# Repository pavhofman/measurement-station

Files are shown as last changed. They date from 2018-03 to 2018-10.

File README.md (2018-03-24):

# Audio Measurement Workstation
## Initial Specifications
- Class II appliance - no ground loops incl. display
- Balanced inputs for measuring bridged or digital amps
- Dedicated device
- Decent measurement quality - PCI soundcard ESI Juli@

## Design Overview
### Thin Client PC FS Futro S900N
- Class II power adapter
- PCI slot incl. +12/-12V supply voltages
- Dual core CPU to allow measurement and VNC remote access
- Connectors for two SATA drives to allow increasing reliability/repairability with RAID1 configuration
- No monitor, keyboard, mouse - access via network VNC
- Current IP address relayed via speech synthesis announcements, using internal soundcard and speaker.
- Inexpensive from ebay

### ESI Juli@
- Both balanced and single-ended inputs and outputs, functioning simultaneously. It allows feeding an amp with single-ended signal and measure balanced speaker output at the same time.
- Digital outputs/inputs for extra measurements/tests
- Full support in linux
- Priced moderately on ebay due to lack of PCI slots in modern PCs

### Software
- Linux Mint Mate (v. 18 at the time of writing)
- Arta measurement software running under wine
- Control - python script hooked to ACPI power button.
  - At startup - Etherner and/or wifi IP addresses are announced.
  - Pushing the power button once - IP addresses announced
  - Pushing the power button twice within two seconds - shutting down + announcement

### Operation
- Measurement mode - remotely via VNC on another PC
- Admin mode - possible to connect monitor/keyboard/mouse at any time

## Construction
All parts are 3D printed, FreeCAD sources and STL models are included in design folder.

Since the thin client supports only half-size PCI cards, room/holes must be made for full-sized one. Upper sound jacks and PS/2 slot must be removed/sawn off.

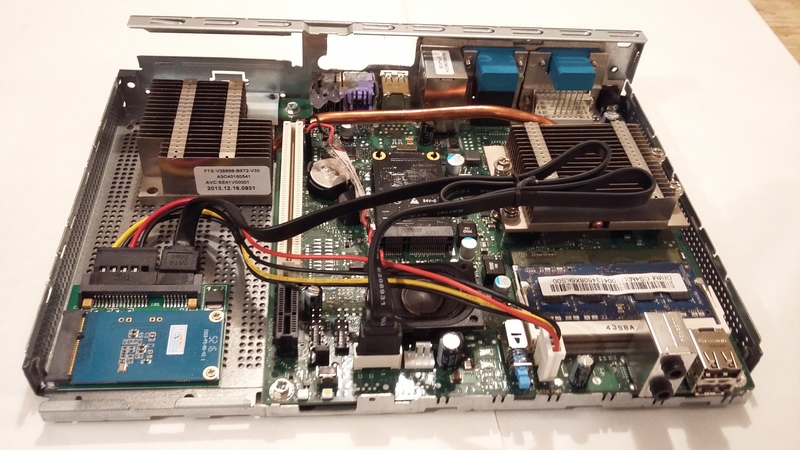
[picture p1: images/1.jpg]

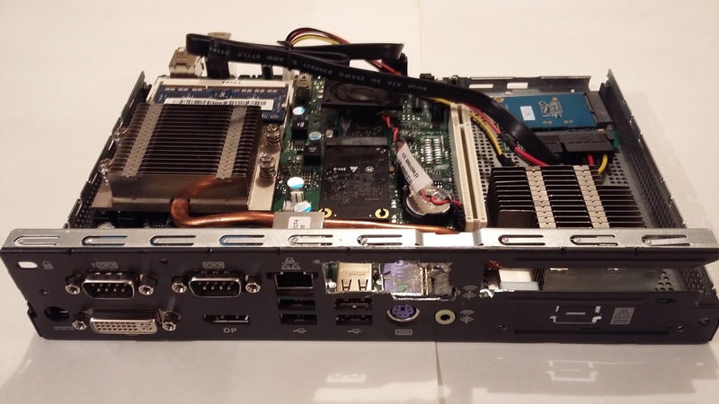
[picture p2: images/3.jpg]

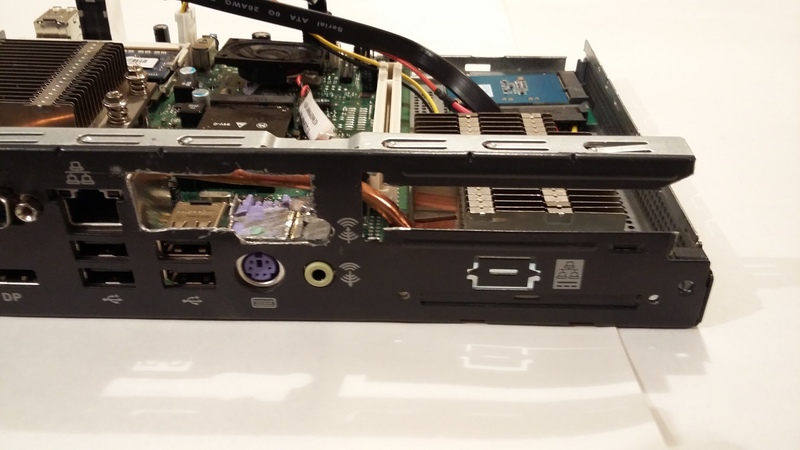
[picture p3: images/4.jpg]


The original holder of the secondary heat sink must be removed, the heat sink fixed directly to the bottom with a new holder.
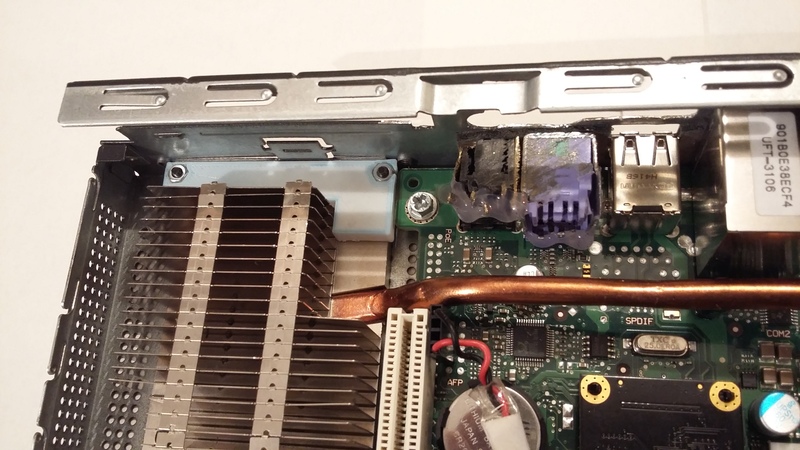
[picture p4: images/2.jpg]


The soundcard is connected with a PCI cable adapter (https://www.aliexpress.com/wholesale?SearchText=19cm+PCI+extension+cable). It is mounted with 3D-printed brackets. The lower brackets provide only shielding, using copper tape connected to the PC enclosure.
Coax digital input and output are extracted from the multiconnector socket to individual add-on cinches.

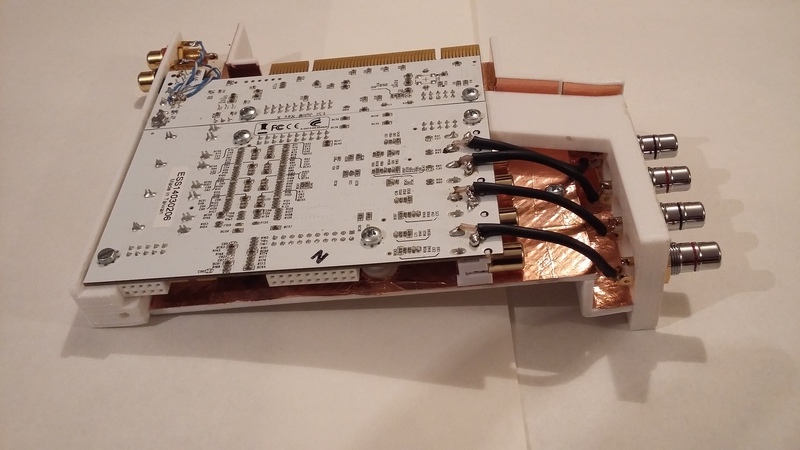
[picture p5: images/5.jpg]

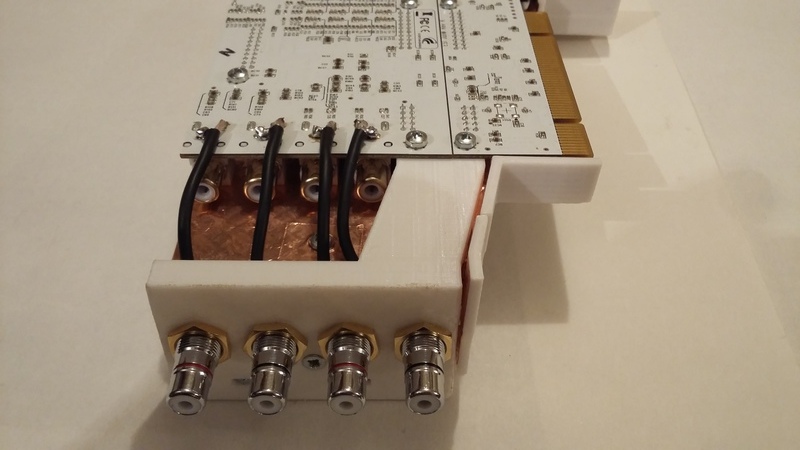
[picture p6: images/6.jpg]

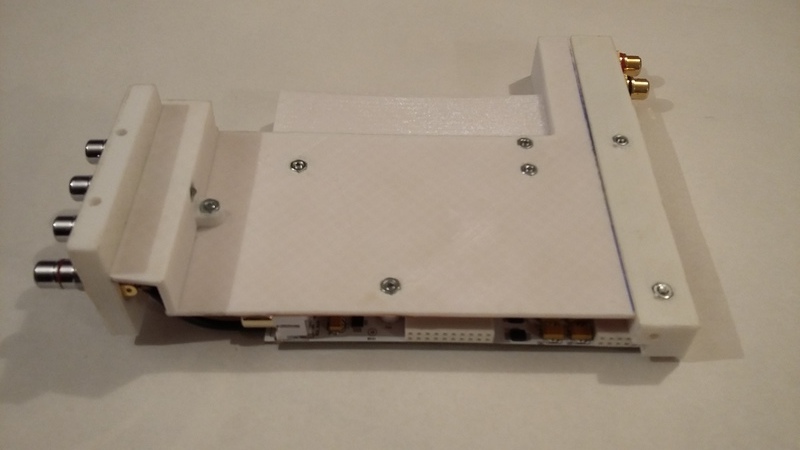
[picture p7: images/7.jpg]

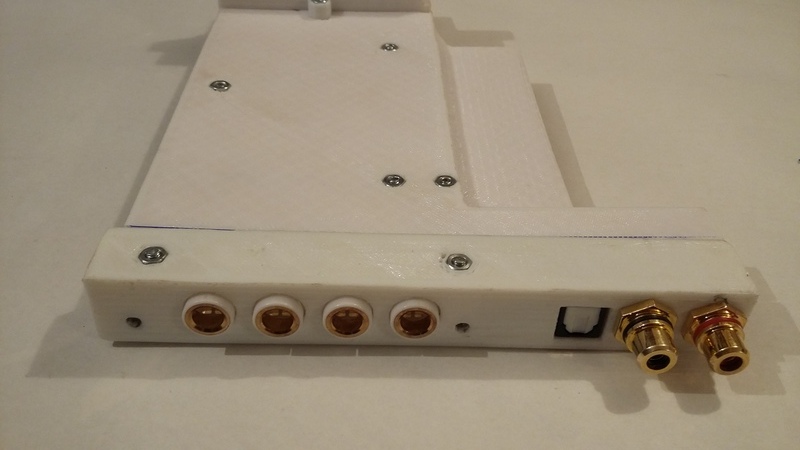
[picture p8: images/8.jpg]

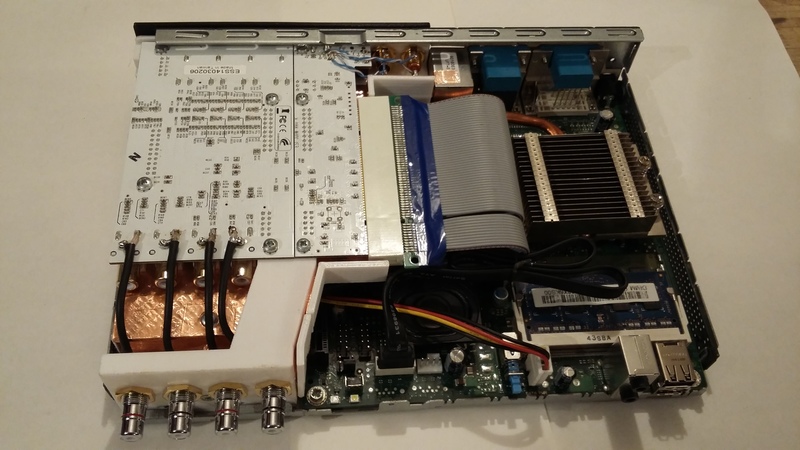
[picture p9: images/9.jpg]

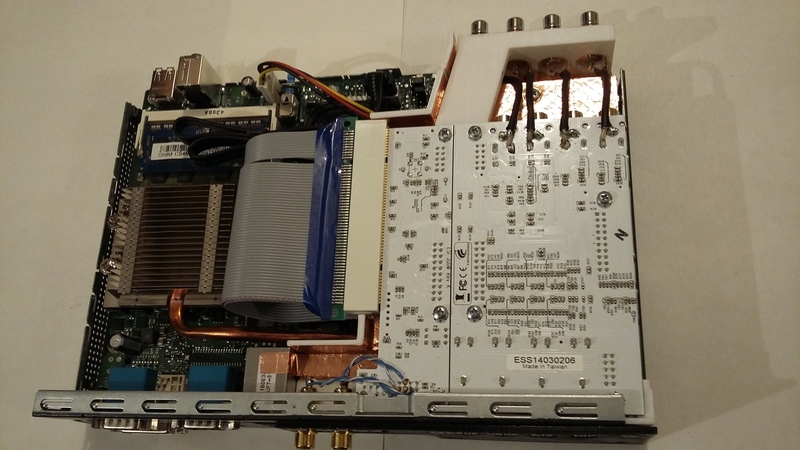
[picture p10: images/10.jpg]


The back panel is printed in two colors.
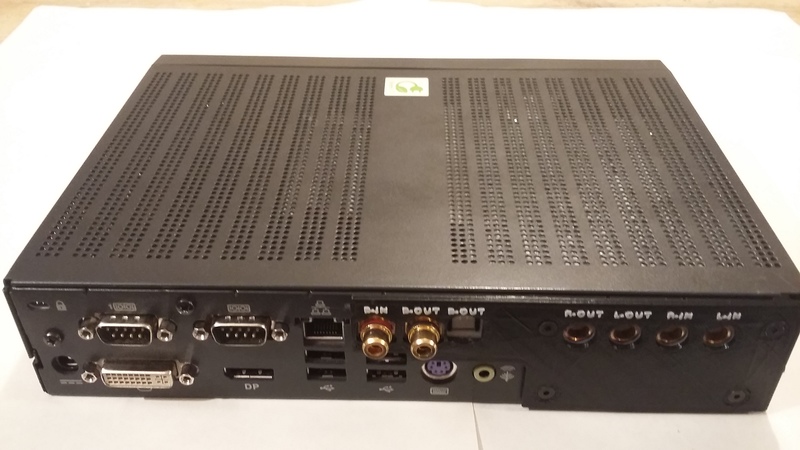
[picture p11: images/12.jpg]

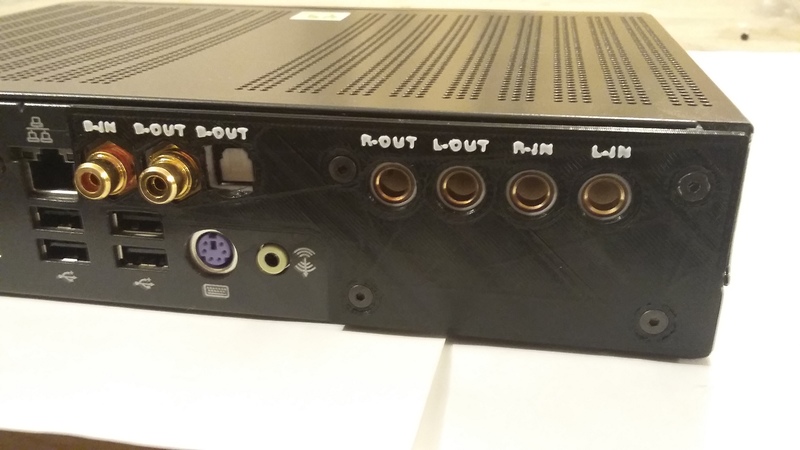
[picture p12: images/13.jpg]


Holes for long cinches are drilled into the front panel, covered with a two-color printed plate.
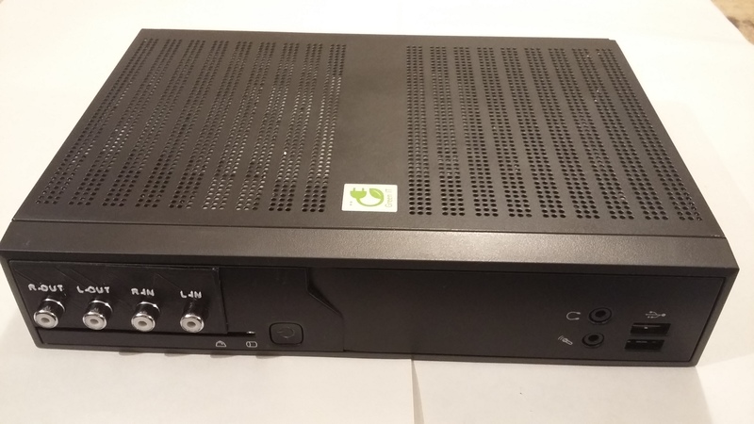
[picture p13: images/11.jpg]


## Performance
Single-ended and balanced inputs are mixed before the ADC. Therefore, for best performance of the higher-voltage balanced inputs short-circuit the more sensitive single-ended inputs with short-circuited cinches. Inexpensive at https://www.ebay.com/sch/i.html?_nkw=RCA+Protective+Caps . In balanced-balanced closed-loop measurement this improves noise RMS from -102dB to -105dBFS.

Closed loop no signal
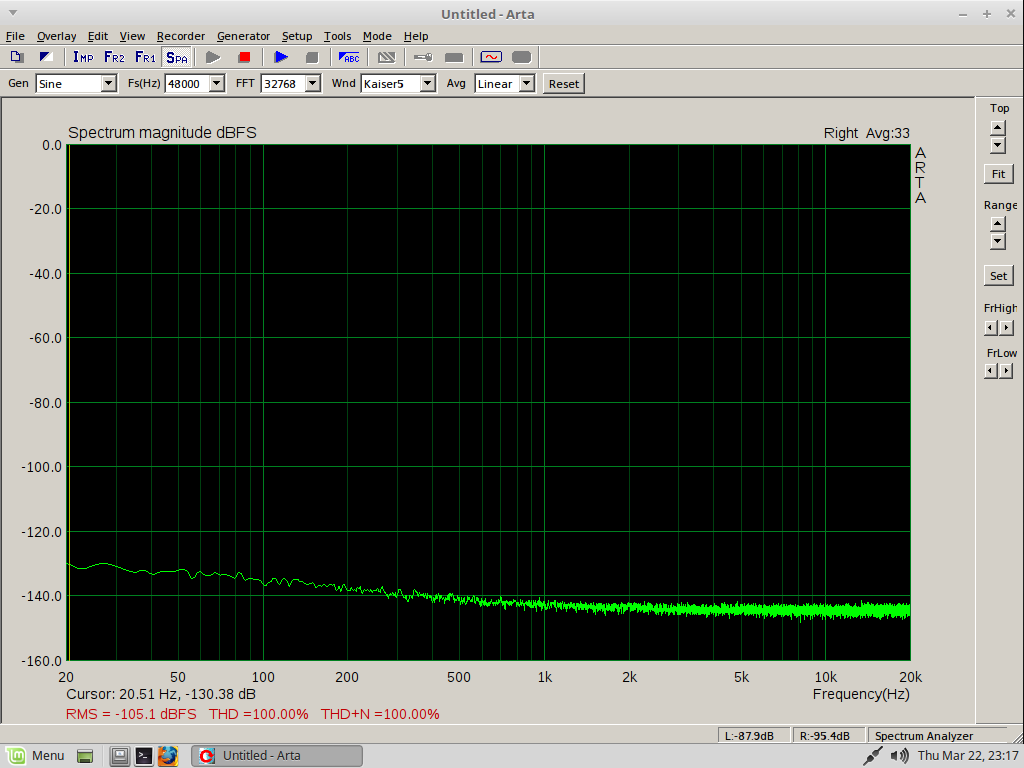
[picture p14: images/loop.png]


Closed loop 1kHz signal
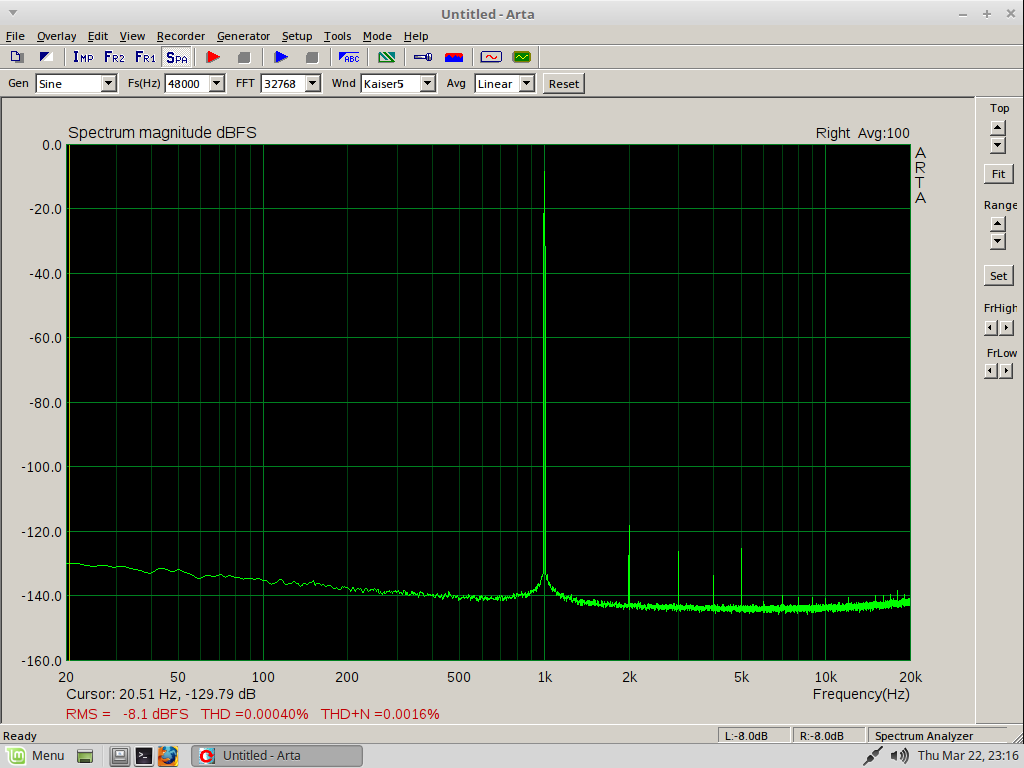
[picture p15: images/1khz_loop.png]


Closed loop two sine 13+14kHz signal
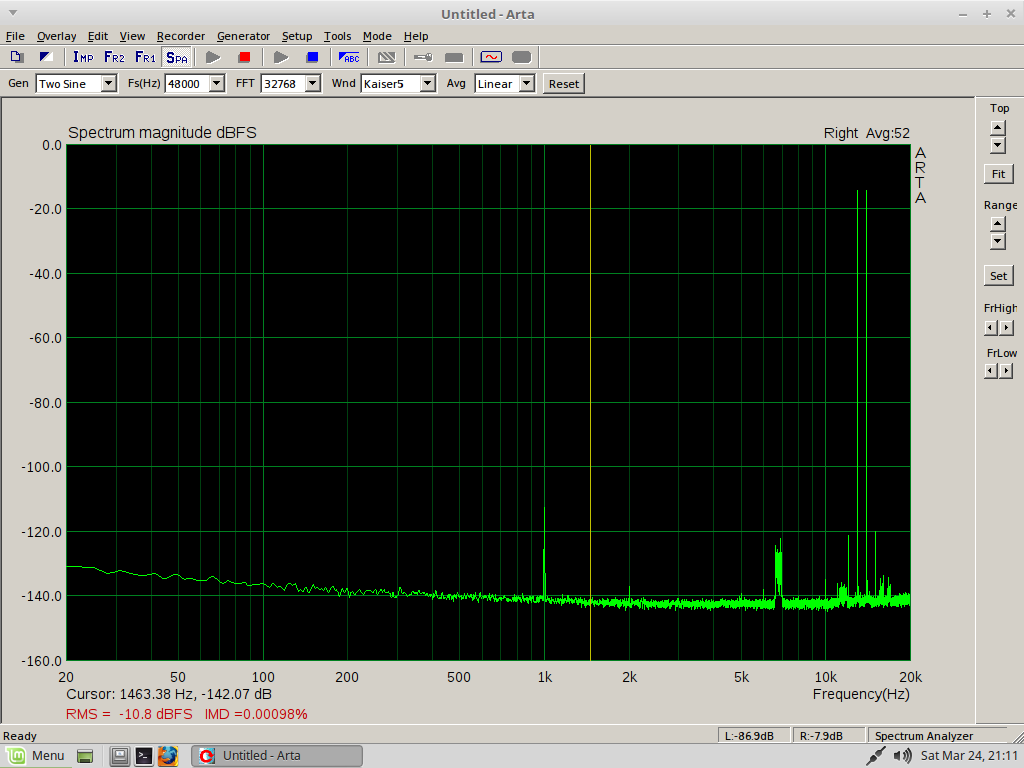
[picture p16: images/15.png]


Amps are measured with a dummy load with replaceable balanced voltage dividers made from old CPU heatsinks, optionally cooled with the original heatsink fans. I will post more pictures and resistor values.
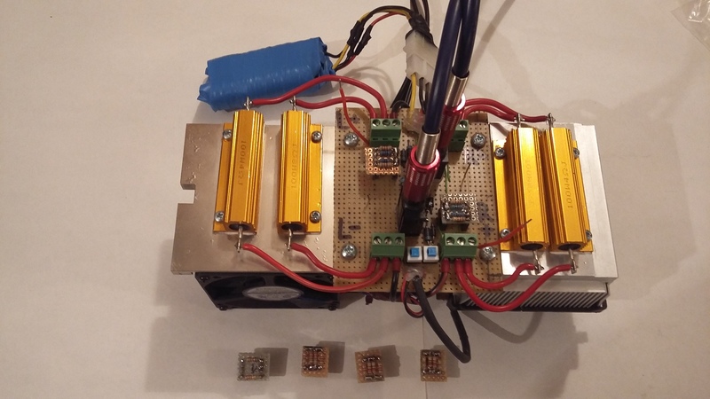
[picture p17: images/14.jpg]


## Notes
### Testing Juli@ Voltage Supplies
The PC generates +12V/-12V voltages for the PCI slot. I cut these supply pins on the connector between digital and ADC/DAC parts of Juli and fed the ADC/DAC part with 7812/7912 linear PSUs. No change in noise background was detected in Arta. It means the internal regulators on Juli are capable of filtering the SMPS-generated supply voltage sufficiently and the PCI-supplied voltages can be used safely.

### Shielding Juli@
I measured the closed-loop noise floor before covering the bottom holders of Juli@ with copper tape and connecting to the case. The difference between the unshielded  and shielded soundcard was less than 0.2dBFS. Therefore I assume the bottom shields are not necessary and do not have to be printed/installed at all.

### No Impact of SSD on Measurement Performance
Running full RAID1 sync on the secondary SSD located right beneath the soundcard had no measurable impact on the closed-loop noise floor of 105.1dBFS.

### VNC Resolution
With no monitor connected the X server starts at 1024x768. This resolution seems just enough for taking measurements/pictures while keeping the CPU load for VNC transmission acceptable.

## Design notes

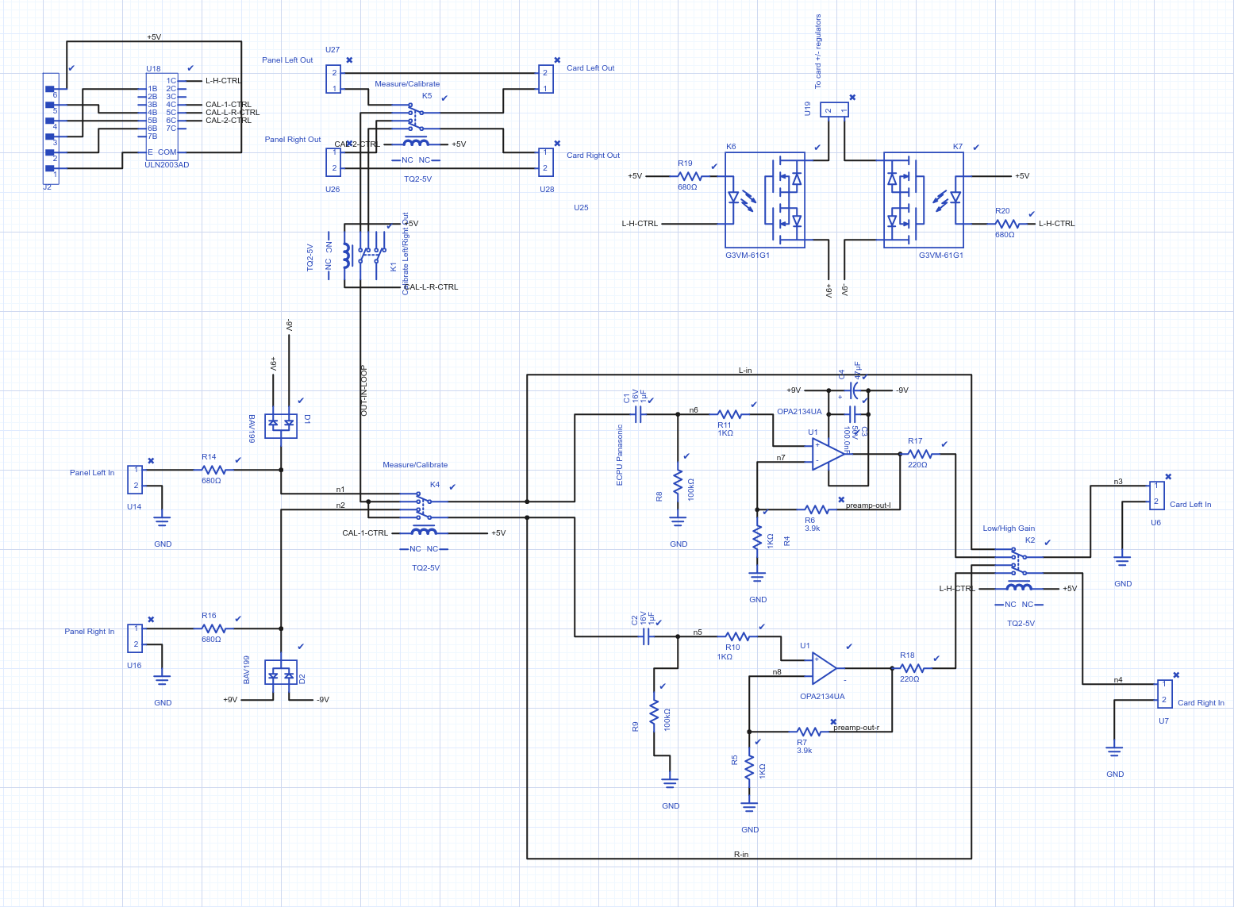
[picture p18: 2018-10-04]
preamp/preamp-schematics.png

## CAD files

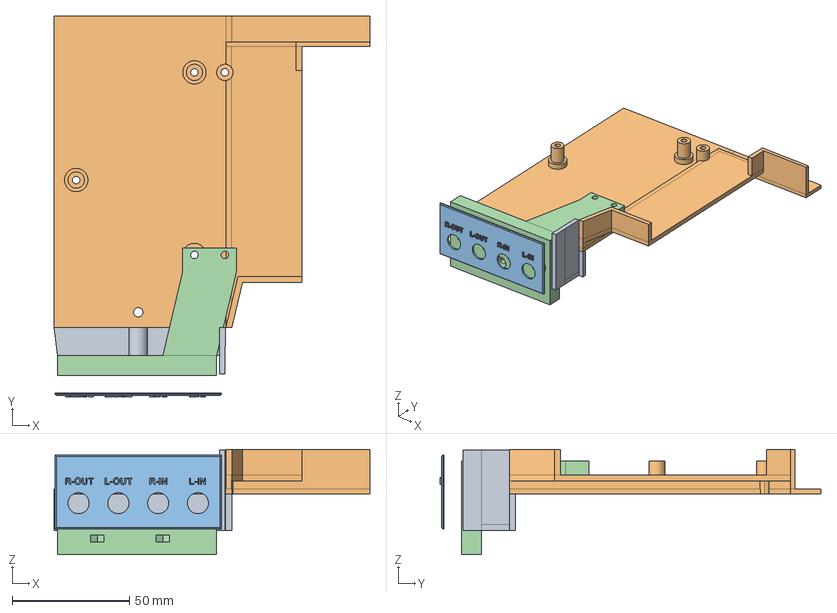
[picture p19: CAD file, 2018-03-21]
designs/assembly.fcstd
135.0 x 162.6 x 45.0 mm
lower shield001 - broken
card-shield
front plate
cinch holder001

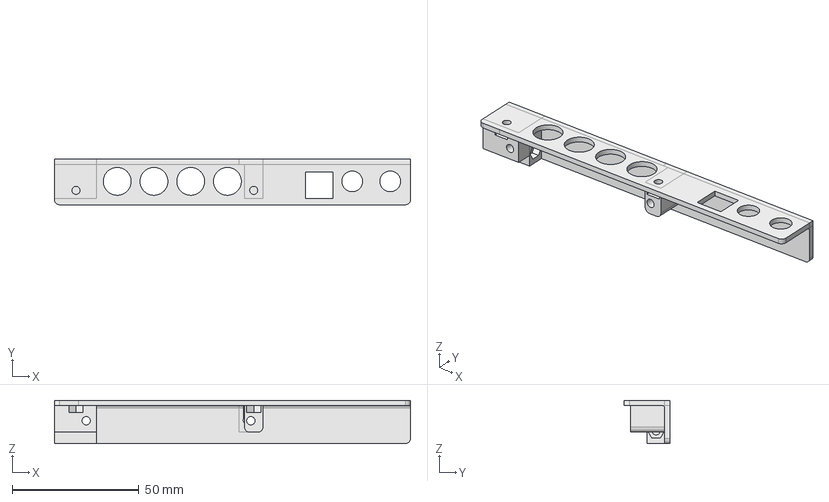
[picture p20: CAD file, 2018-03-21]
designs/juli-bracket.fcstd
140.5 x 18.0 x 17.0 mm

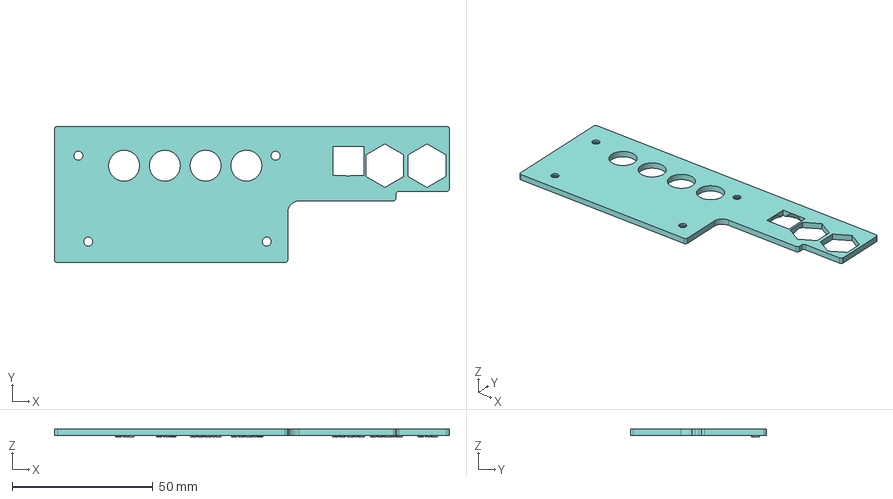
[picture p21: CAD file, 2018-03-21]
designs/back-plate.fcstd
140.5 x 48.5 x 3.00 mm
Extrude-D-IN
Extrude-D-OUT-C
Extrude-D-OUT-O
Extrude-R-OUT
Extrude-L-OUT
Extrude-R-IN
Extrude-L-IN

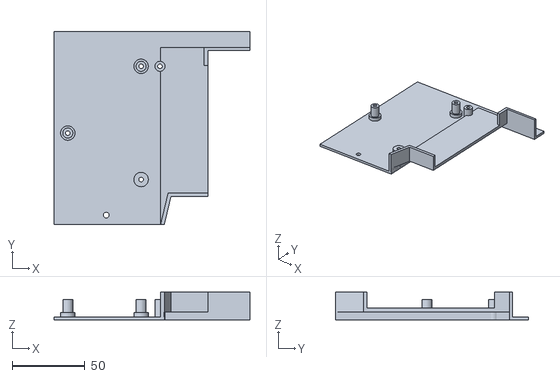
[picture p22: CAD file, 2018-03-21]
designs/card-shield.stl
135.0 x 133.0 x 19.0

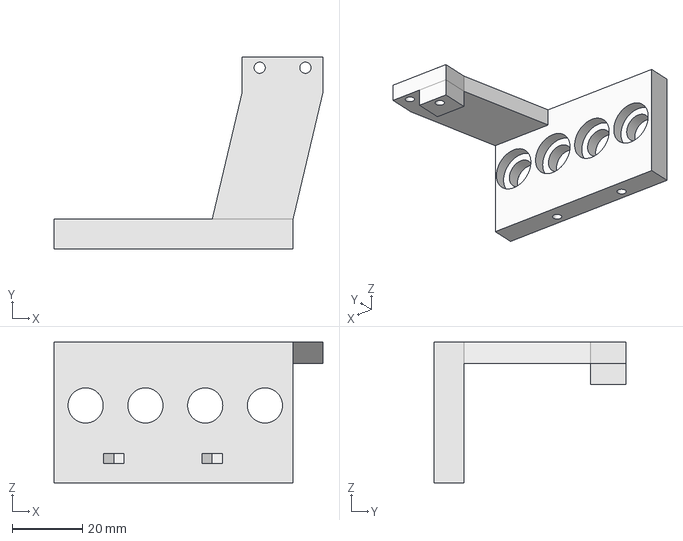
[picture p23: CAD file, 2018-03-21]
designs/cinch-holder.fcstd
76.5 x 54.5 x 40.0 mm

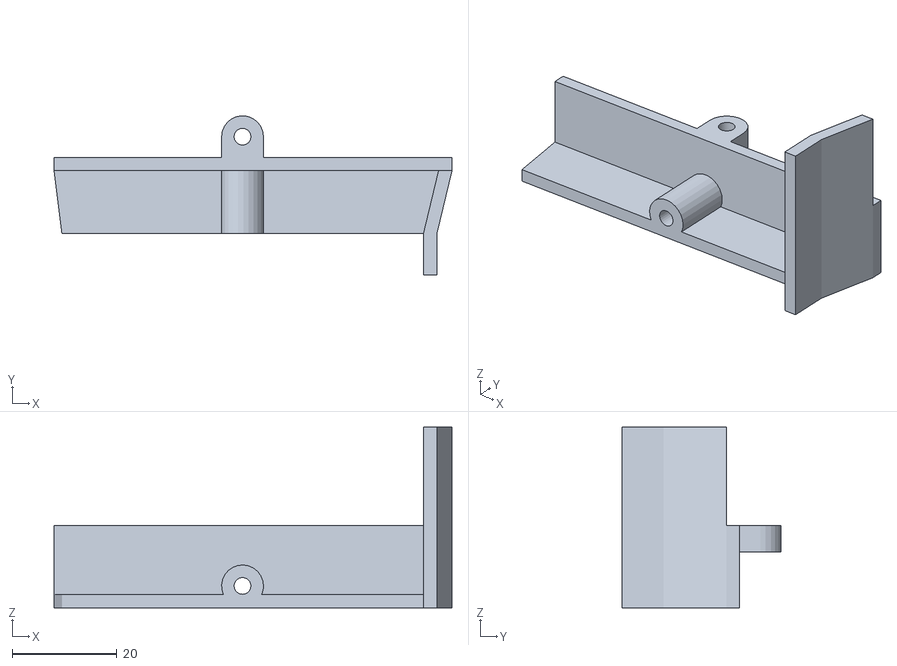
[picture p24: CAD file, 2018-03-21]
designs/lower-shield.stl
76.0 x 30.5 x 34.5

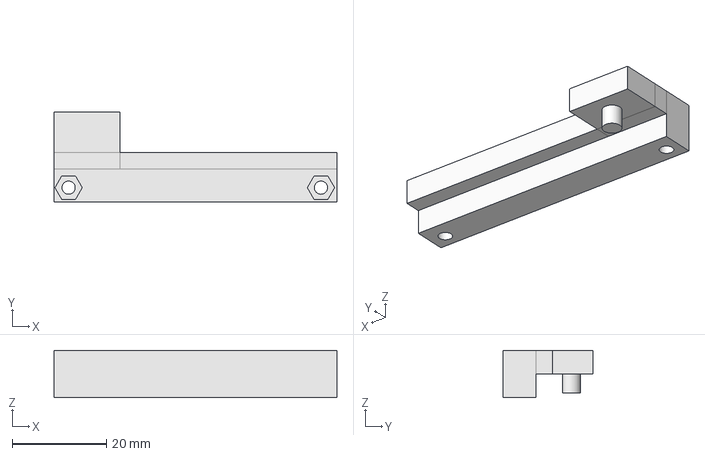
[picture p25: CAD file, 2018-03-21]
designs/cooler-holder.fcstd
60.0 x 19.0 x 10.0 mm

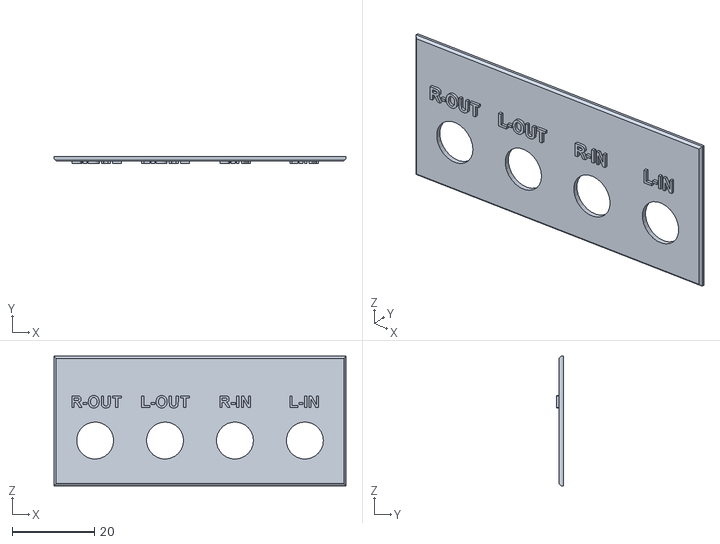
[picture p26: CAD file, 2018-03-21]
designs/front-plate.stl
71.0 x 1.60 x 31.5

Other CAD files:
designs/back-plate.stl
designs/cinch-holder.stl
designs/cooler-holder.stl
designs/juli-bracket.stl

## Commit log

2018-09-30 PREAMP - initial schematics
2018-10-04 update schematics
